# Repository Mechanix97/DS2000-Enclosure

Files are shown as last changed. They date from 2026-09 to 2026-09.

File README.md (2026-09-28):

<p align="center">
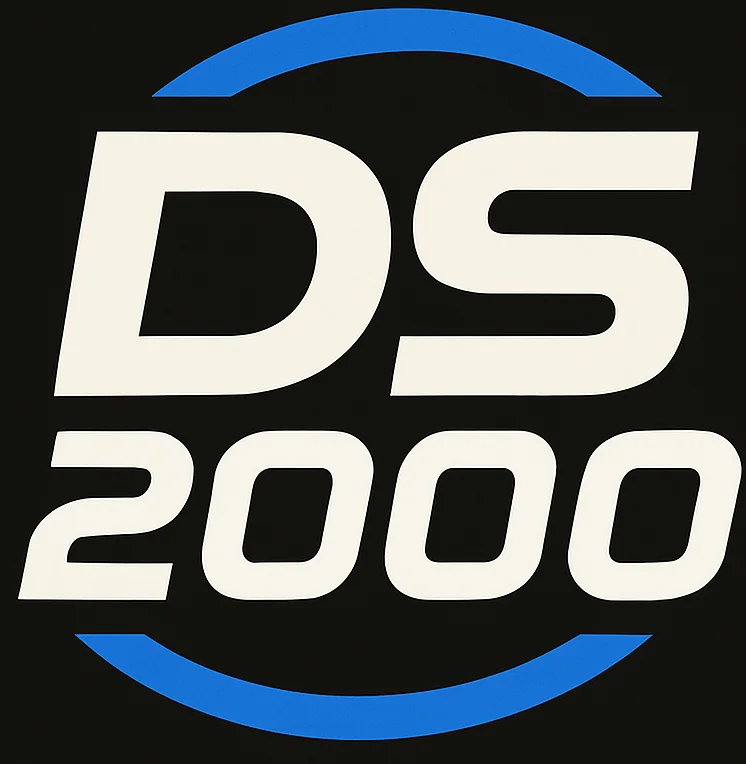
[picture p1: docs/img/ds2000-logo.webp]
DS2000
  
</p>

# DS2000 Enclosure

3D-printed tray for the [DS2000](https://github.com/Mechanix97/DS2000), a three-key Discord control
deck. The PCB is the device's visible top face; the enclosure is the tray it sits in, screwed through
the board's four corner holes.

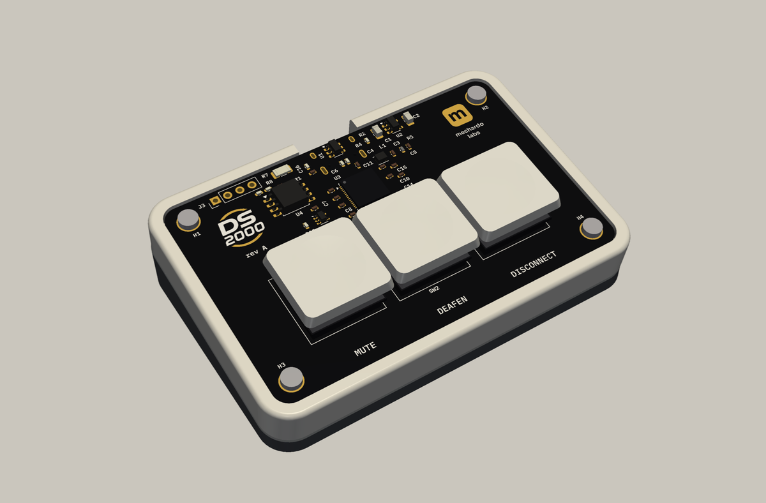
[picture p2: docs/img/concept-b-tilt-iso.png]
Concept B on the 7° wedge


Modelled in **Fusion 360**. Fusion stores designs in the cloud, so this repository keeps exports
that anyone can use without a Fusion licence.

## Design: concept B, frame

The board sits recessed in a frame whose lip rises 0.6 mm above its top face, on four M2 bosses.
The keys are Kailh Choc V1 with flat MBK-style caps. **The same tray works in two ways**: flat on
rubber feet, or on a separate 7° wedge held by four 6 × 1.5 mm magnets. The USB-C stays at the back in
both. Details in [`docs/requirements.md`](docs/requirements.md).

| Flat | On the 7° wedge |
|---|---|
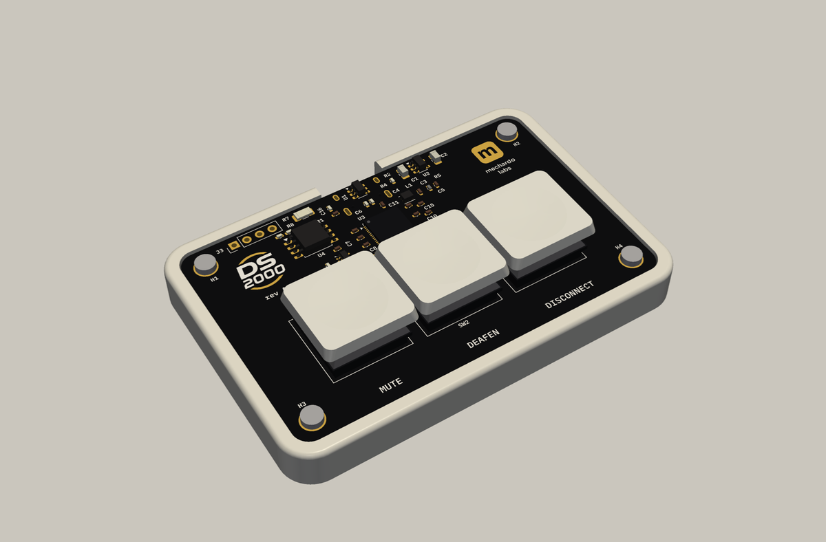
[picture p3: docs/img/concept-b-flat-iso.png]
Flat
|  | Tilted |
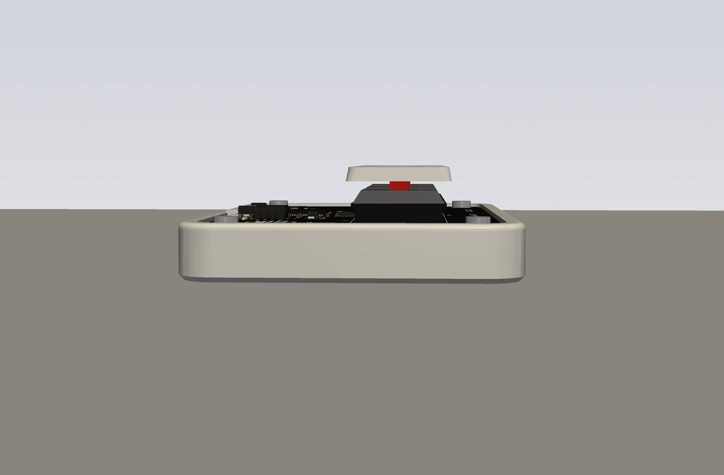
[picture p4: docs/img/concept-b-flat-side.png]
Flat, side
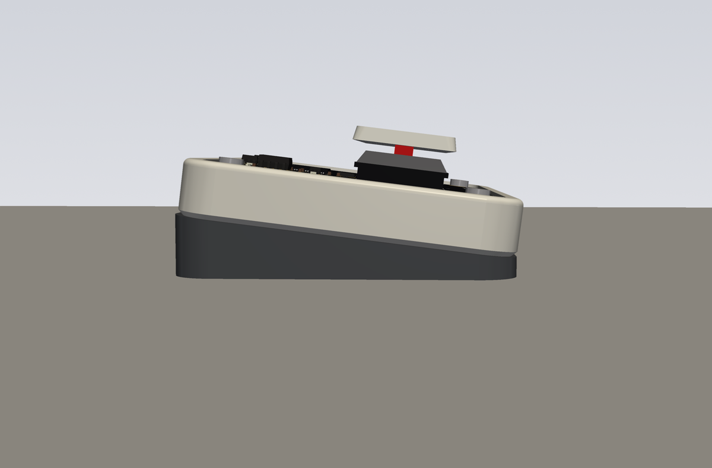
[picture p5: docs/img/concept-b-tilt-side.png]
Tilted, side
|  |  |
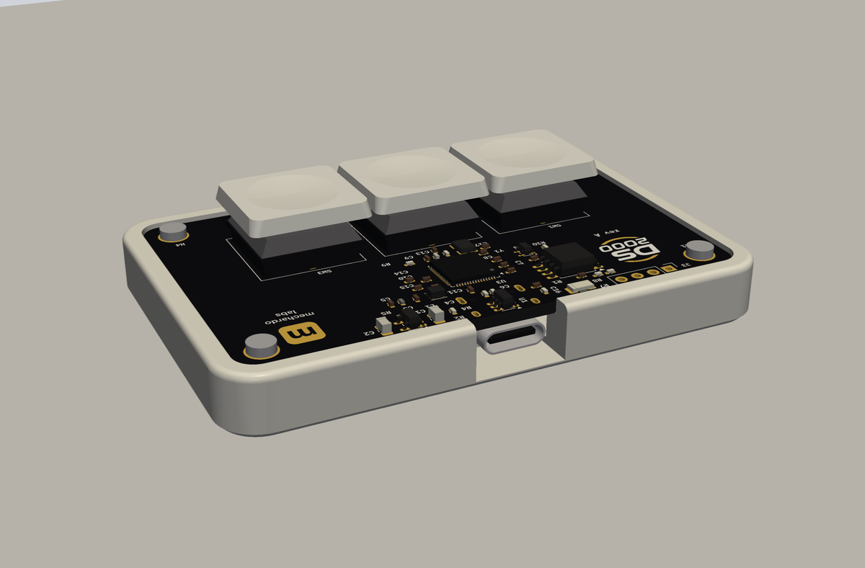
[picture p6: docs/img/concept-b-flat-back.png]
Flat, back
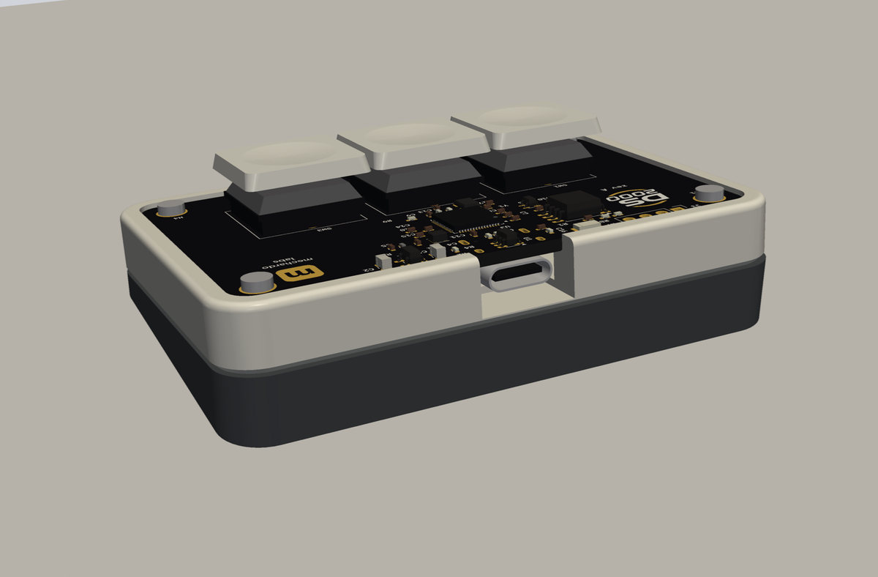
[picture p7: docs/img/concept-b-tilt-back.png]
Tilted, back
|  |  |

These are the concept renders from [`tools/concepts/`](tools/concepts/), made to pick a direction.
The final model is built in Fusion 360.

<details>
<summary>The three concepts considered (#1)</summary>

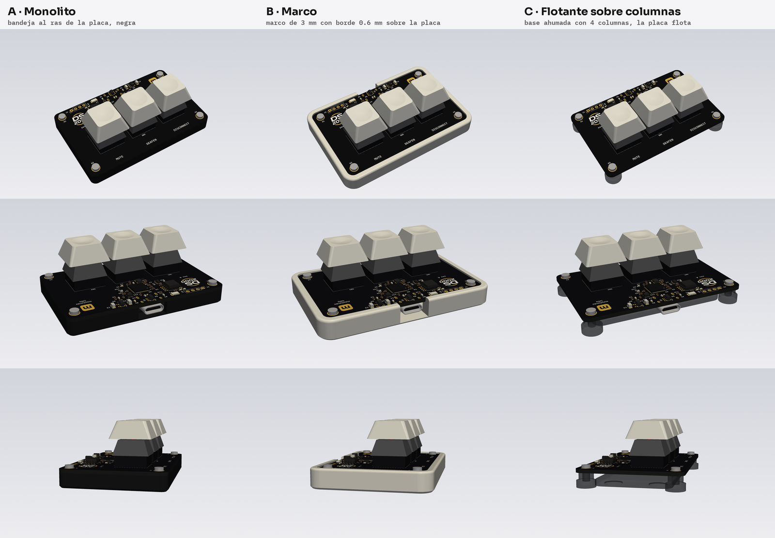
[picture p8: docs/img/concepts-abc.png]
Concepts A, B and C


A, a monolith that follows the board outline; **B, a frame (chosen)**; C, the board floating on
columns over a smaller base.
</details>

## Layout

| Folder | Contents |
|---|---|
| `cad/` | Fusion 360 archives (`.f3d` / `.f3z`) of the enclosure |
| `step/` | STEP of the enclosure (and of the full assembly) |
| `print/` | Printable parts (`.stl` / `.3mf`) with orientation and settings |
| `pcb/` | The board as a solid model and its mechanical reference, pinned to a PCB revision |
| `docs/` | Requirements, renders (`docs/img/`), assembly guide, BOM |
| `tools/` | Concept scripts (build123d + pyvista) |

CAD and print files live in Git LFS (`.gitattributes`); run `git lfs install` once before cloning.

## Related repositories

- [DS2000](https://github.com/Mechanix97/DS2000): desktop application
- [DS2000-Firmware](https://github.com/Mechanix97/DS2000-Firmware): firmware
- [DS2000-PCB](https://github.com/Mechanix97/DS2000-PCB): board (KiCad)

## License

AGPL-3.0, see [`LICENSE`](LICENSE), like the rest of the DS2000 project.

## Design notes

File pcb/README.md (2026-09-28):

# DS2000-PCB rev A — mechanical reference

`DS2000-PCB-revA.step` is the populated rev A board, exported from
[DS2000-PCB](https://github.com/Mechanix97/DS2000-PCB) at commit `045842b` (DS2000-PCB#19, rev A with
Kailh Choc V1 keys; re-export and update this line once it is merged) with:

```sh
kicad-cli pcb export step --user-origin 100x94mm --subst-models -o DS2000-PCB-revA.step DS2000.kicad_pcb
```

It includes every part, the three Choc V1 switches with an MBK-style keycap on each, and the USB-C receptacle
underneath. Re-export it whenever the board's outline, holes or parts change, and note the PCB
commit here: the enclosure and the board share these numbers.

## Axes

Same as the STEP, so the file drops into Fusion 360 without moving it:

- **origin**: the board's centre, on its **bottom** face
- **X** to the right, seen from the user
- **Y** towards the **back** (the USB-C edge); the user sits at −Y
- **Z** up; the board's top face is at Z = 1.6

## Board

| | |
|---|---|
| Outline | 72 × 46 mm, X −36…+36, Y −23…+23, 3 mm corner radius |
| Thickness | 1.6 mm (4 layers) |
| Top face | black soldermask, the product's visible face: logos, key legends, the RP2350A on show |

## Mounting holes

Four M2, plated, tied to GND (the screws ground the tray's metal hardware if any).

| Hole | X | Y |
|---|---|---|
| H1 back left | −32 | +19 |
| H2 back right | +32 | +19 |
| H3 front left | −32 | −19 |
| H4 front right | +32 | −19 |

Drill 2.2 mm, copper ring 4.4 mm on both faces: keep screw heads and standoffs within 4.4 mm.

## Keys

| Key | Centre X | Centre Y |
|---|---|---|
| MUTE | −18 | −7.0 |
| DEAFEN | 0 | −7.0 |
| DISCONNECT | +18 | −7.0 |

- Kailh Choc V1 (low profile), soldered, no plate: the switch housing sits on the board's top face
  (13.8 mm lower housing, 15 mm flange 2.2 mm up, housing top at Z ≈ 6.6)
- keycap: MBK-style, 17.5 × 16.5 mm, 18 mm pitch, top at **Z ≈ 10.3** (1.6 board + ~8.7; real
  caps vary by a few tenths), 3 mm of travel
- the keys are fully exposed: nothing of the enclosure should rise above the board's top face
  within a keycap's footprint plus ~1 mm

## Underneath (what the tray has to clear)

| Item | Where | Below the board (Z) |
|---|---|---|
| USB-C receptacle | X −4.47…+4.47, Y +16.9…+24.2 (face 1.2 mm past the back edge) | 0 … **−3.35** |
| Choc switch pins and posts | under each key | 0 … −3.0 (centre post Ø3.4, side posts Ø1.9) |
| SK6812MINI-E ×2 | under MUTE and DEAFEN (X −18 and 0, Y −11.7) | flush |
| Debug pads (SWD, BOOT, RST) | X +18…+23.1, Y +13…+17 | flat pads |
| USB wire holes (J3) | X −25.5…−17.9, Y +21 | through-holes |

- **Pocket depth**: at least **4 mm** under the whole board (USB-C plus margin), more if a weight or
  foam goes underneath
- **Back wall**: a cut-out for the USB-C plug's overmould, centred on X = 0, Z ≈ −1.7 (the
  receptacle's centre); overmoulds are commonly up to 12.5 × 6.5 mm, so leave at least 13 × 7 mm
- **Debug pads** are covered by the tray. Either the board comes off to reach them, or a small window
  goes under X +16…+25, Y +11…+19
- If J3 is used (soldered cable instead of the receptacle), the cable leaves from Y +21 near the back
  left and needs its own exit

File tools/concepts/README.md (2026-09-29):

# Concept models and renders

Parametric sketches (build123d) of the enclosure concepts in #1, rendered with pyvista. They are for
choosing a direction and fitting the board, not the final design, which is modelled in Fusion 360.

| Script | What |
|---|---|
| `concepts.py` | The three first concepts: A monolith, B frame, C floating |
| `concept_b_versions.py` | Concept B (chosen) flat and on a separate 7° wedge; exports `B_tray.step` and `B_wedge.step` |
| `exploded.py` | Exploded view of concept B: screws, board, tray, wedge |
| `render_variants.py` | Product renders for [mechardo3d.xyz](https://mechardo3d.xyz): 4 views × 3 colourways (negro, original, snes), 1536 × 1024 on the site's gallery background; writes `out/site/<colour>-<view>.png` |

The renders need a board STEP with the copper, mask and silkscreen:

```sh
kicad-cli pcb export step --user-origin 100x94mm --subst-models --include-tracks --include-pads \
  --include-zones --include-silkscreen --include-soldermask -o tools/concepts/pcb_render.step DS2000.kicad_pcb
pip install build123d pyvista
python tools/concepts/concept_b_versions.py pcb_render.step     # writes tools/concepts/out/
python tools/concepts/render_variants.py                          # site renders, from pcb_render.step
```

The site ships them as WebP (`static/images/DS2000/renders/` in mechardo3d):

```sh
python -c "from PIL import Image; import glob, os; [Image.open(f).convert('RGB').save(os.path.basename(f)[:-4] + '.webp', quality=86, method=6) for f in glob.glob('tools/concepts/out/site/*.png')]"
```

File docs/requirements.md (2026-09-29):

# Enclosure requirements

Draft for #2. The board side is fixed (see [`pcb/README.md`](../pcb/README.md)); the open items are
decisions for the enclosure itself.

## Fixed by the board

- **Concept**: the PCB is the visible top face; the enclosure is a tray underneath it. Nothing covers
  the face: the logos, key legends and the RP2350A are meant to be seen
- **Fixing**: four M2 screws through the board's corner holes (±32, ±19)
- **Footprint**: at least the board's 72 × 46 mm; the tray may extend past it (a lip or bezel) as
  long as it stays below the board's top face
- **Clearance underneath**: ≥ 4 mm pocket; USB-C cut-out in the back wall, ≥ 13 × 7 mm, centred on
  the receptacle
- **Height**: keycap tops sit ~10.3 mm above the board's bottom face (Choc V1 + MBK); the tray adds to that

## Decided

- **Concept B, frame**: a bezel around the board with a lip 0.6 mm above its top face; the board sits
  recessed in it on four bosses (M2 into heat-set inserts). See [`img/concept-b-versions.png`](img/concept-b-versions.png)
- **Keys**: Kailh Choc V1 low profile with flat MBK-style caps, after the Chudx Nano 100 (DS2000-PCB#19)
- **Two versions of B, same tray**:
  - **flat**: the tray on its pads; the USB-C cable leaves straight back, level with the desk
  - **tilted**: the tray on a separate wedge, 7°, 3.0 mm at the front and 9.4 mm at the back, held by
    four 6 × 1.5 mm disc magnets under the corner bosses, with pockets matched in the wedge. The USB-C
    stays at the back and the cable leaves at 7°; a cable soldered to J3 is the alternative
- **Pads**: 8 × 3 mm self-adhesive silicone bumpers, four on the tray and four on the wedge. The tray's
  sit in 8.4 × 1.2 mm recesses at (±24, ±14) and stand 1.8 mm proud; the wedge's top face has 8.6 ×
  2.1 mm recesses where they land, so the tray lies flat on it and the magnets meet. The wedge's own
  pads sit in 8.4 × 0.8 mm recesses in its underside
- **Modelled** in Fusion 360 (#14, #15): the tray and the wedge are generated by the scripts in
  [`cad/scripts/`](../cad/scripts/), and those scripts hold every dimension above

## To decide

- [ ] Printer and process (FDM / resin), material (PLA, PETG, ASA…)
- [ ] Tray height under the board (6.5 mm as modelled: 4.5 mm pocket + 2 mm floor; the floor also
      holds the 1.2 mm pad recesses and the 1.6 mm magnet pockets)
- [ ] Screws: M2 into heat-set inserts (as modelled) or self-tapping into plastic
- [ ] Weight: a steel or lead weight in the pocket (keys get pressed hard during calls); the pads
      are decided
- [ ] Access to the debug pads: take the board out, or a window in the floor
- [ ] Keycaps: MBK colour, and whether mute/deafen are translucent (their LEDs shine through the switch)
- [ ] Colour and finish of the tray, to go with the black-and-gold board

## Deliverables

- Fusion 360 archive in `cad/`, STEP of the enclosure and of the assembly in `step/`
- printable parts in `print/` with orientation and settings, and the hardware BOM (#6)

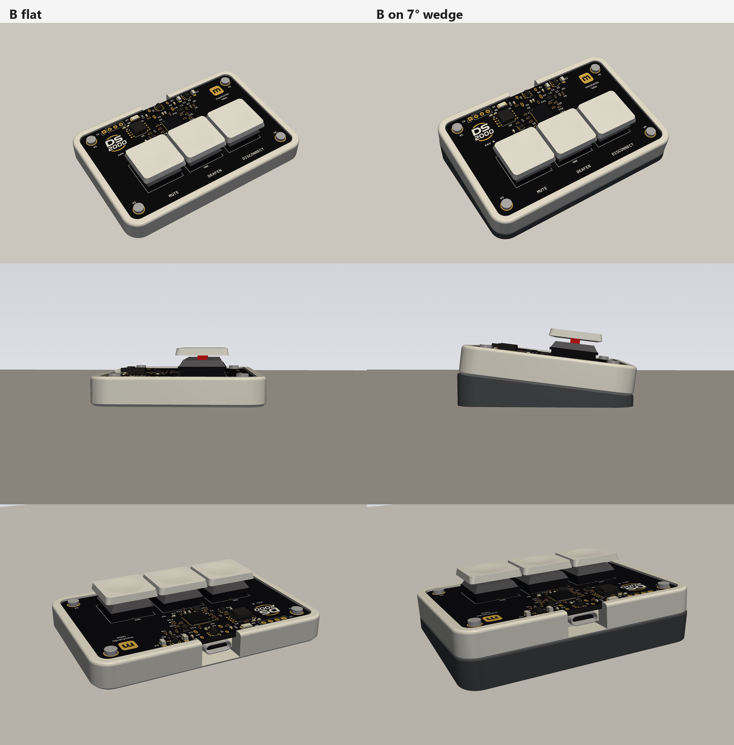
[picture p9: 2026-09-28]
docs/img/concept-b-versions.png

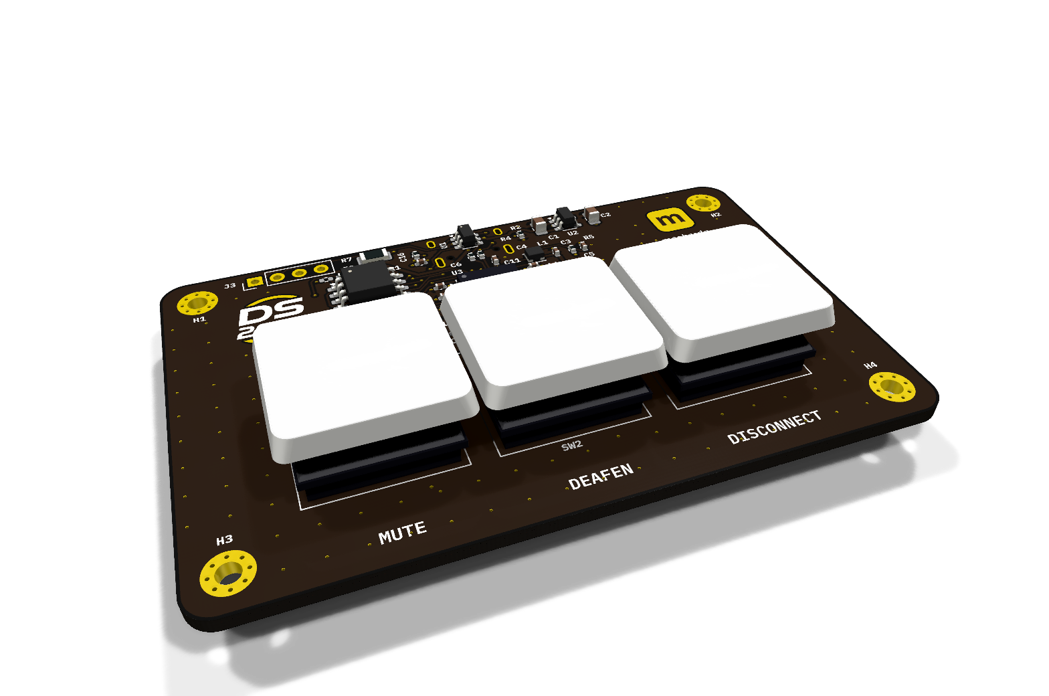
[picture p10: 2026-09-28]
docs/pcb-rev-a.png

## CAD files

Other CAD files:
pcb/DS2000-PCB-revA.step
step/ds2000-wedge.step
step/ds2000-tray.step
step/concept-b-tray.step
step/concept-b-wedge.step
cad/ds2000-tray.f3d
cad/ds2000-wedge.f3d
print/ds2000-tray.3mf
print/ds2000-wedge.3mf

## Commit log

2026-09-28 chore: set up the repository for Fusion 360 sources and printable exports
    Folders for Fusion archives, STEP, printable parts, the board's mechanical reference and docs.
    CAD and print formats go through Git LFS. AGPL-3.0, like the rest of the project.
2026-09-28 feat: add the rev A board model and its mechanical reference
    pcb/DS2000-PCB-revA.step is the populated board (switches and keycaps included) exported from
    DS2000-PCB b65971f, centred on the board with Y towards the USB-C edge, so it drops into Fusion
    360 as is. pcb/README.md lists what the tray must match: outline, the four M2 holes, key centres,
    and everything underneath with its depth (USB-C 3.35 mm, switch pins 1.8 mm), plus the USB-C plug
    cut-out and access to the debug pads.
    docs/requirements.md drafts the enclosure requirements: what the board fixes and what is still to
    decide.
    [DS2000-PCB-revA.step]
2026-09-28 feat: concept B flat and on a 7 degree wedge, with the Choc V1 board
    - board model re-exported from DS2000-PCB#19 (Kailh Choc V1, 18 mm pitch, keys at Y -7)
    - mechanical reference and requirements updated: concept B decided, one tray for a flat
    version on feet and a tilted one on a separate magnet-held wedge
    - concept scripts (build123d + pyvista), STEP sketches of the tray and wedge, comparison render
    [DS2000-PCB-revA.step, concept-b-tray.step, concept-b-wedge.step]
2026-09-29 feat: product renders for the website in three colourways
    render_variants.py makes the mechardo3d.xyz DS2000 gallery: concept B on its 7 degree wedge in four
    views (front, back, top, exploded) and three colourways (black, cream, SNES), 1536 x 1024 on the
    site's gallery background. exploded.py is the exploded view used in the PCB README.
2026-09-29 feat: SNES colourway with the North American console's colours
    Light grey shell, dark grey base, lavender (X/Y) keys for MUTE and DEAFEN and the deep purple of
    A/B for DISCONNECT, instead of the Super Famicom's four button colours.
2026-09-29 feat: concept B tray modelled in Fusion 360, with the script that generates it
    The tray of concept B (frame around the rev A board) as a Fusion 360 archive, with its STEP and 3MF
    exports, and the Fusion Python script that builds it from the dimensions in tools/concepts.
    [ds2000-tray.3mf, ds2000-tray.f3d, ds2000-tray.step]
2026-09-29 feat: 7 degree wedge, and pad recesses sized for 8 x 3 mm bumpers
    The wedge for the tilted version, modelled in Fusion 360 with the script that generates it: 78 x 52 mm,
    3.0 mm at the front and 9.4 mm at the back. Its top face takes the four magnet pockets under the tray's
    bosses and four recesses where the pads glued to the tray land (8.6 mm, 2.1 mm deep), so the tray lies
    flat and the magnets meet; its underside takes its own four pads. The top-face cuts are drawn in the
    tray's frame and tilted onto the wedge, rather than sketched on the sloped face.
    The pads are 8 x 3 mm self-adhesive silicone bumpers on both parts. The tray's pad recesses go from
    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
    [ds2000-tray.3mf, ds2000-tray.f3d, ds2000-tray.step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]
2026-09-29 docs: record the pads and the Fusion model in the requirements
    The 8 x 3 mm silicone bumpers and their recesses in the tray and the wedge move to Decided, the flat
    version stands on those pads, and the grip item is left with the weight alone. Tray height and screws
    point at what was modelled.
2026-10-29 docs: bring the PCB interface up to the production-review board
    Re-export the board STEP from DS2000-PCB f9ae589 (PR #29) and update
    the README's underneath table: J3 is now SMD wire pads beside the USB-C
    cut-out, the LEDs moved to the top inside the switches, the key centre
    hole is 4 mm, MX prototype pins stick out ~1.7 mm, and TP4-TP6 are new.
